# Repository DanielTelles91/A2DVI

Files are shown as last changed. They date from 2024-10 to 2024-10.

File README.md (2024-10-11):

# A2DVI - Apple II Digital Video

This is a project for a digital DVI/HDMI Apple II video card.
It directly produces a digital video stream from Apple II's memory content.
The signal is output via an HDMI connector, connecting the Apple II to modern displays with HDMI (or DVI) inputs.
No more analog signal conversion required.

The project is a collaboration with Thorsten Brehm. His related firmware project is here: https://github.com/ThorstenBr/A2DVI-Firmware

For the DVI output to be active, the new firmware developed by Thorsten should be used.

The card also has an alternative analog VGA connector.
For the VGA output to be active, the [VGA firmware](https://github.com/markadev/AppleII-VGA) developed by Mark Aikens should be used.

The card can produce either an analog VGA or a digital HDMI signal, but not both simultaneously.
To switch between modes, a firmware update is required and opening/closing connections.

Captura de tela 2024-10-10 230457
Captura de tela 2024-10-10 230504
Captura de tela 2024-10-10 230522
Captura de tela 2024-10-10 230530

## Dual-Language Support
The pin on the v1.5 and later boards is for AltChr connection, supported by A2DVI firmware for switching between alternative character sets on non-US versions of Apple II ("Euro-machines").

# Hardware
* Based on the PICO controller board.
* Provides a DVI video stream via an HDMI connector.
* Low power/heat dissipation: less than 70mA@5V = 0.35W in operation.
* Uses 4x 74LV245 bus transceivers for 5V/3.3V signal conversion of the Apple II bus.
* Separate ALTCHR input pin for dual-language support: pin needs to be wired separately to the "language switch" of Euro-Apple IIs (optional).

# Thanks
This is a project based on:

* the AppleII-VGA project by Mark Aikens - https://github.com/markadev/AppleII-VGA

* the PicoDVI project by Luke Wren - https://github.com/Wren6991/PicoDVI

* Thorsten Brehm for firmware development and board design considerations

* Oliver Schmidt on original idea discussions and design considerations

# License
Board design by Ralle Palaveev (c) 2024.

All rights reserved.

Redistribution and use in source, binary, and manufactured forms, with or without
modification, are permitted provided that the following conditions are met:
1. Redistributions of source code and design files must retain the above copyright
   notice, this list of conditions and the following disclaimer.
2. Redistributions in binary or manufactured form must reproduce the above copyright
   notice, this list of conditions and the following disclaimer in the
   documentation and/or other materials provided with the distribution.
3. All advertising materials mentioning features or use of this software
   or hardware must display the following acknowledgement:
   This product includes software or hardware developed by Ralle Palaveev.
4. Neither the name of Ralle Palaveev nor the
   names of its contributors may be used to endorse or promote products
   derived from this software or hardware without specific prior written permission.

The above copyright notice and this permission notice shall be included in all
copies or substantial portions of the Software.

THE SOFTWARE IS PROVIDED "AS IS", WITHOUT WARRANTY OF ANY KIND, EXPRESS OR
IMPLIED, INCLUDING BUT NOT LIMITED TO THE WARRANTIES OF MERCHANTABILITY,
FITNESS FOR A PARTICULAR PURPOSE AND NONINFRINGEMENT. IN NO EVENT SHALL THE
AUTHORS OR COPYRIGHT HOLDERS BE LIABLE FOR ANY CLAIM, DAMAGES OR OTHER
LIABILITY, WHETHER IN AN ACTION OF CONTRACT, TORT OR OTHERWISE, ARISING FROM,
OUT OF OR IN CONNECTION WITH THE SOFTWARE OR THE USE OR OTHER DEALINGS IN THE
SOFTWARE.

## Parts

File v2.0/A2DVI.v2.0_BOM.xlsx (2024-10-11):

Comment | Designator | Footprint | JLCPCB Part #（optional）
HDMI connector | HDMI1 |  | C7501808
PinHeader_1x01_P2.54mm_Horizontal | H1 |  | C2883838
270 | R1,R2,R3,R4,R5,R6,R7,R8 | 0402 | C25099
10k | R9,R10,R11,R12 | 0402 | C25744
16V 100nF X7R ±10% 0402 Multilayer Ceramic Capacitors MLCC - SMD/SMT ROHS | C1,C2,C3,C4,C5,C6 | 0402 | C1525
10V 100uF X5R ±20% 1210 Multilayer Ceramic Capacitors MLCC - SMD/SMT ROHS | C7 | 1210 | C386065
MBR120VLSFT1G | D1 | SOD123-FL | C223608
6V 100mA Resettable Fuse | Fu1 | 0805 | C20975
Raspberry Pi PICO | U1 |  | C7203002
SN74LVC245APWR | U2,U3,U4,U5 | TSSOP-20 | C7848

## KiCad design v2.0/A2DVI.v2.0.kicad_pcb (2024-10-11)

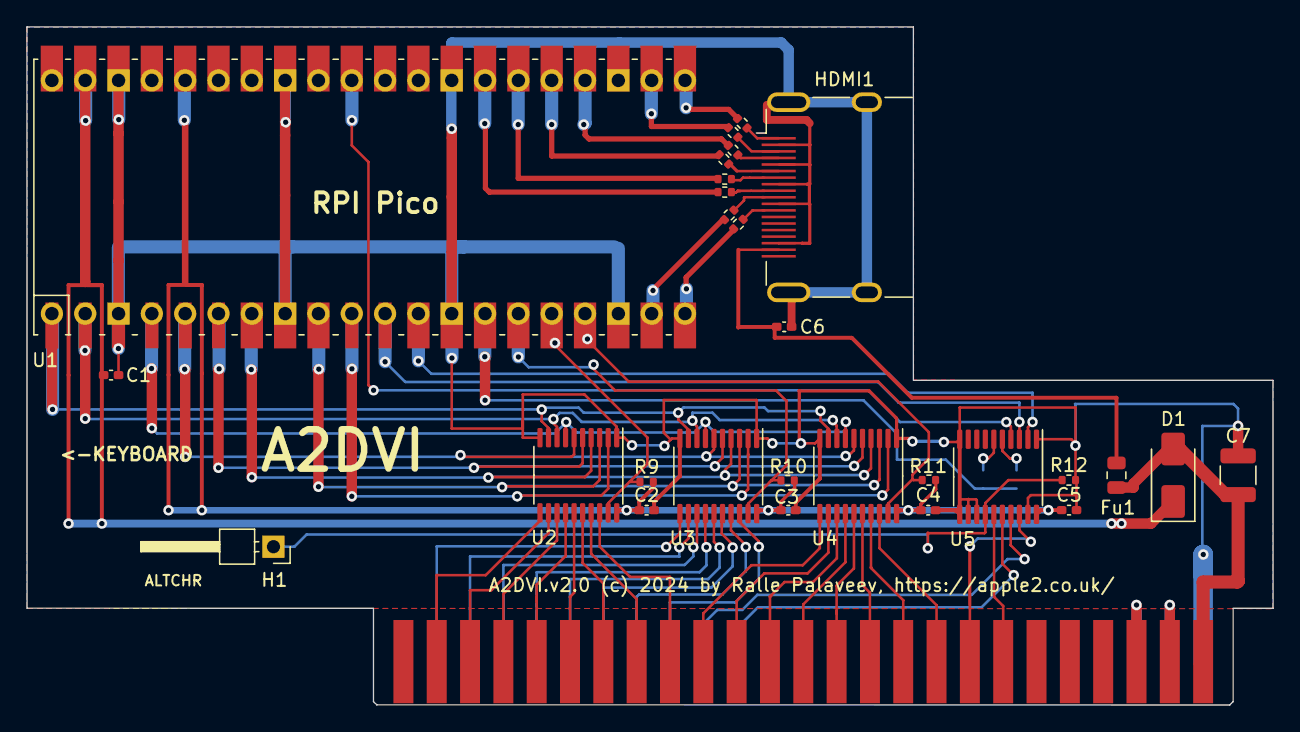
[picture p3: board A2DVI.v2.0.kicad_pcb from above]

Board: 2 copper layers, 95.0 x 51.7 mm, 28 parts (0 on the bottom side), 29 nets.

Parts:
C1, C2, C3, C4, C5, C6: 100n; C_0402_1005Metric_Pad0.74x0.62mm_HandSolder
C7: C_1210_3225Metric
D1: SS16; D_SMA
Fu1: Fuse_0805_2012Metric
H1: PinHeader_1x01_P2.54mm_Horizontal
HDMI1: HDMI_A_Molex_208658-1001_Horizontal
R1, R2, R3, R4, R5, R6, R7, R8: 270; R_0402_1005Metric
R9, R10, R11, R12: 10k; R_0402_1005Metric
U1: Pico; RPi_PicoW_SMD_TH
U2, U3, U4, U5: SN74LVC245APWR; TSSOP-20_4.4x6.5mm_P0.65mm

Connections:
3.3V: C2.1, C3.1, C4.1, C5.1, R9.2, R10.2, R11.2, U1.36 (3V3), U2.20, U3.20, U4.20, U5.20
5V: C7.2, D1.2, Fu1.2
5V_out: C6.1, Fu1.1, HDMI1.18
AD0: U1.1 (GPIO0), U2.9, U3.9, U4.9
AD1: U1.2 (GPIO1), U2.8, U3.8, U4.8
AD2: U1.4 (GPIO2), U2.7, U3.7, U4.7
AD3: U1.5 (GPIO3), U2.6, U3.6, U4.6
AD4: U1.6 (GPIO4), U2.5, U3.5, U4.5
AD5: U1.7 (GPIO5), U2.4, U3.4, U4.4
AD6: U1.9 (GPIO6), U2.3, U3.3, U4.3
AD7: U1.10 (GPIO7), U2.2, U3.2, U4.2
Altchr: H1.1, R12.1, U5.14
CK_N: R8.1, U1.20 (GPIO15)
CK_P: R7.1, U1.19 (GPIO14)
D0_N: R6.1, U1.27 (GPIO21)
D0_P: R5.1, U1.26 (GPIO20)
D1_N: R4.1, U1.25 (GPIO19)
D1_P: R3.1, U1.24 (GPIO18)
D2_N: R2.1, U1.22 (GPIO17)
D2_P: R1.1, U1.21 (GPIO16)
D2_otut_P: HDMI1.1, R1.2
DATAOE: R10.1, U1.15 (GPIO11), U3.19
GND: C1.2, C2.2, C3.2, C4.2, C5.2, C6.2, C7.1, HDMI1.2, HDMI1.5, HDMI1.8, HDMI1.11, HDMI1.17, HDMI1.SH, R12.2, U1.3 (GND), U1.8 (GND), U1.13 (GND), U1.18 (GND), U1.23 (GND), U1.28 (GND), U1.33 (AGND), U1.38 (GND), U2.1, U2.10, U3.1, U3.10, U4.1, U4.10, U5.1, U5.10, U5.11, U5.12, U5.13, U5.19
L-DevSel: U1.11 (GPIO8), U5.3
L-PHI0: U1.31 (GPIO26_ADC0), U5.4
L-RW: U1.12 (GPIO9), U5.2
LSBOE: R9.1, U1.16 (GPIO12), U2.19
MSBOE: R11.1, U1.17 (GPIO13), U4.19
VSYS: C1.1, D1.1, U1.39 (VSYS)

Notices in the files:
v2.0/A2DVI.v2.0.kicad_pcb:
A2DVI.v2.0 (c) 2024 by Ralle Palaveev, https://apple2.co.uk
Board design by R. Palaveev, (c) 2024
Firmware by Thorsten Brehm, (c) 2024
